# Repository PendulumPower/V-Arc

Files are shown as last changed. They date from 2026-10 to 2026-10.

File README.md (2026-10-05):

# V-ARC (WIP)
V-ARC is a multi-effects pedal, preamp, ble page turner, and looper designed for electric violin. It can also be used for other electric
instruments such as guitar. It runs on 2 separate controllers and includes a Lipo battery. It will be capable of being wirelessly reprogrammed for convienience,
and should have an app later in development so that settings can be tweaked or effects swapped without interacting with it. It is also going to feature MIDI conversion
and wireless playback in the future.
<br>Images:
<br>Schematic:
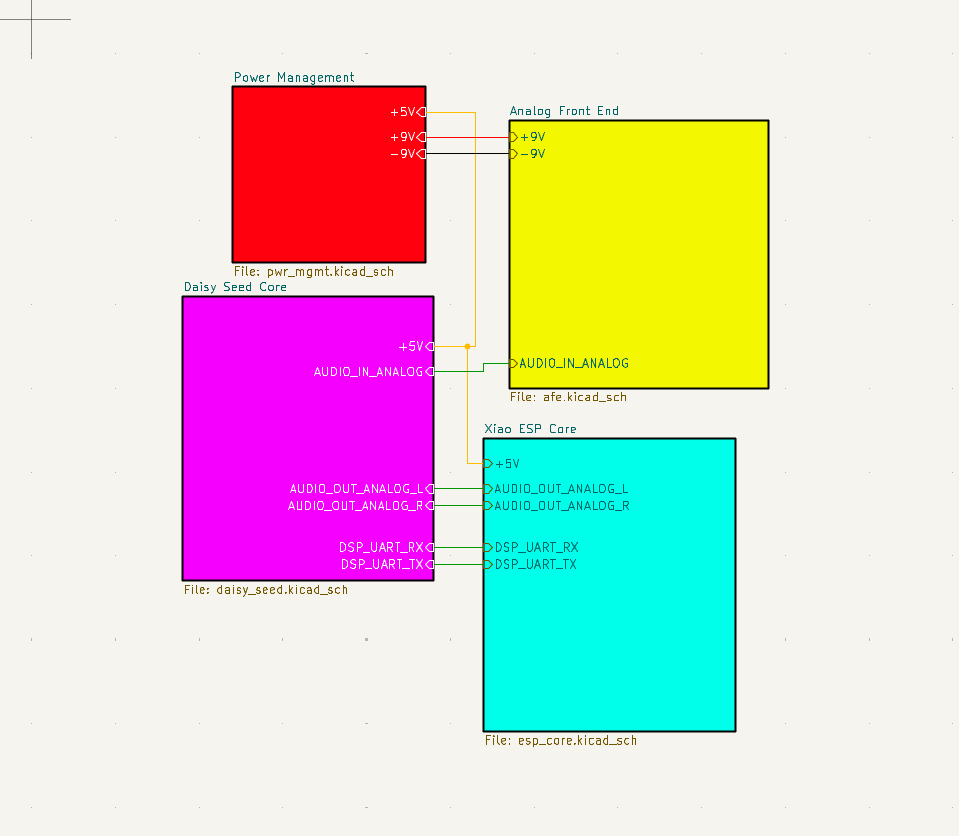
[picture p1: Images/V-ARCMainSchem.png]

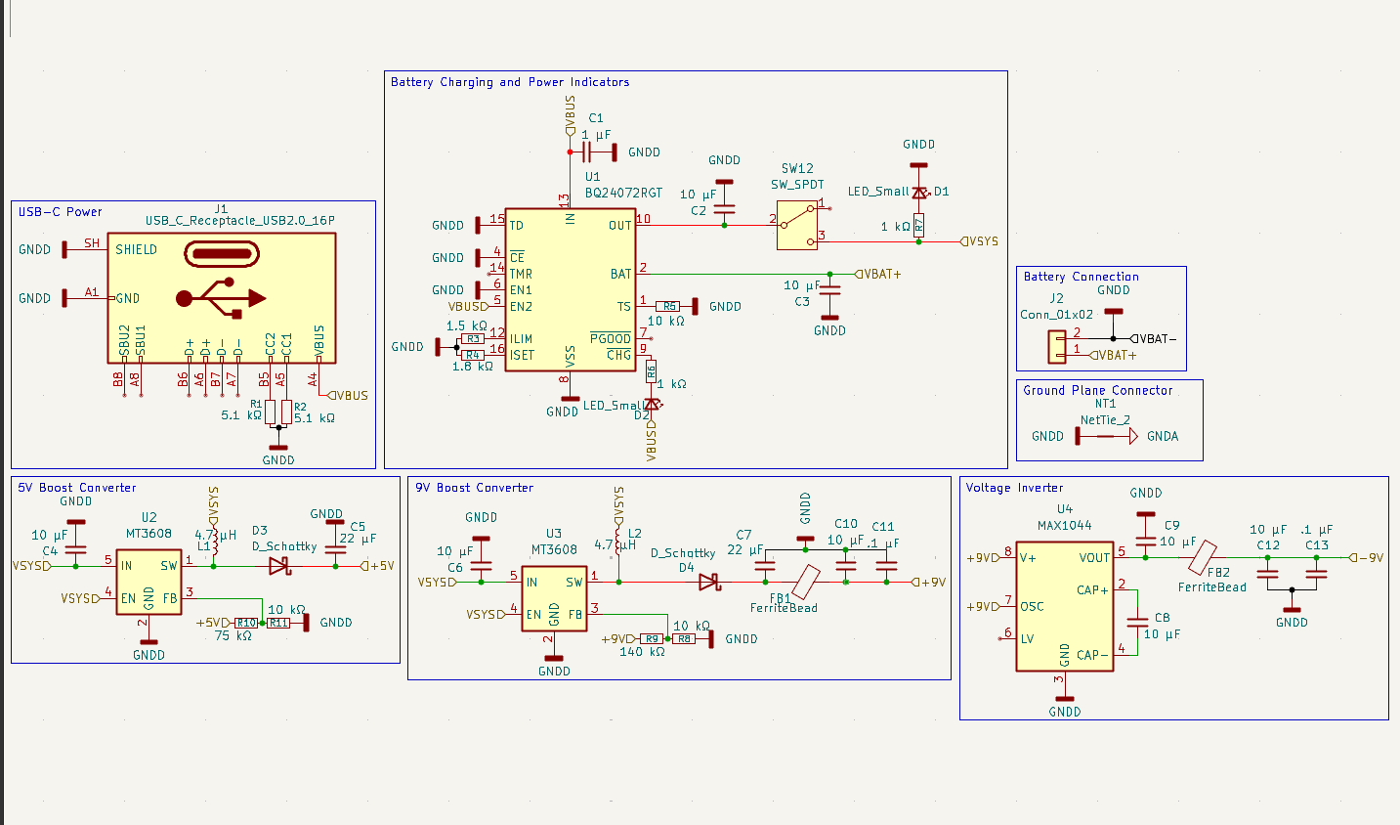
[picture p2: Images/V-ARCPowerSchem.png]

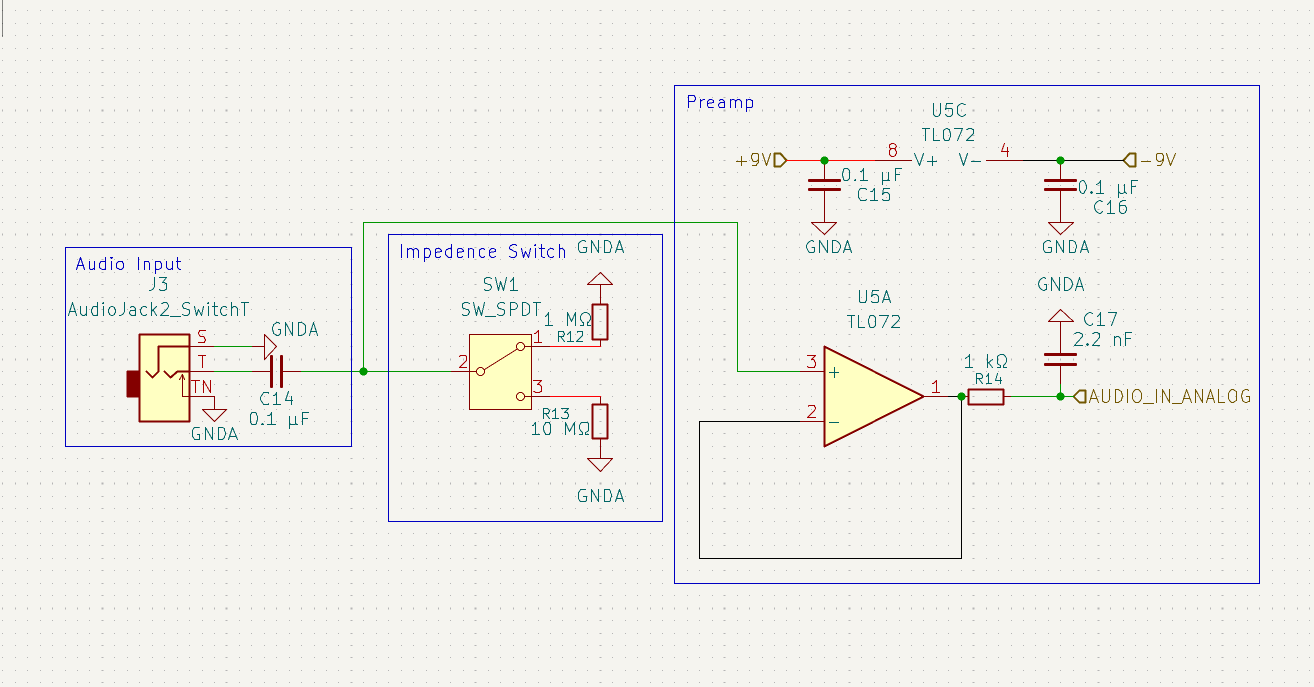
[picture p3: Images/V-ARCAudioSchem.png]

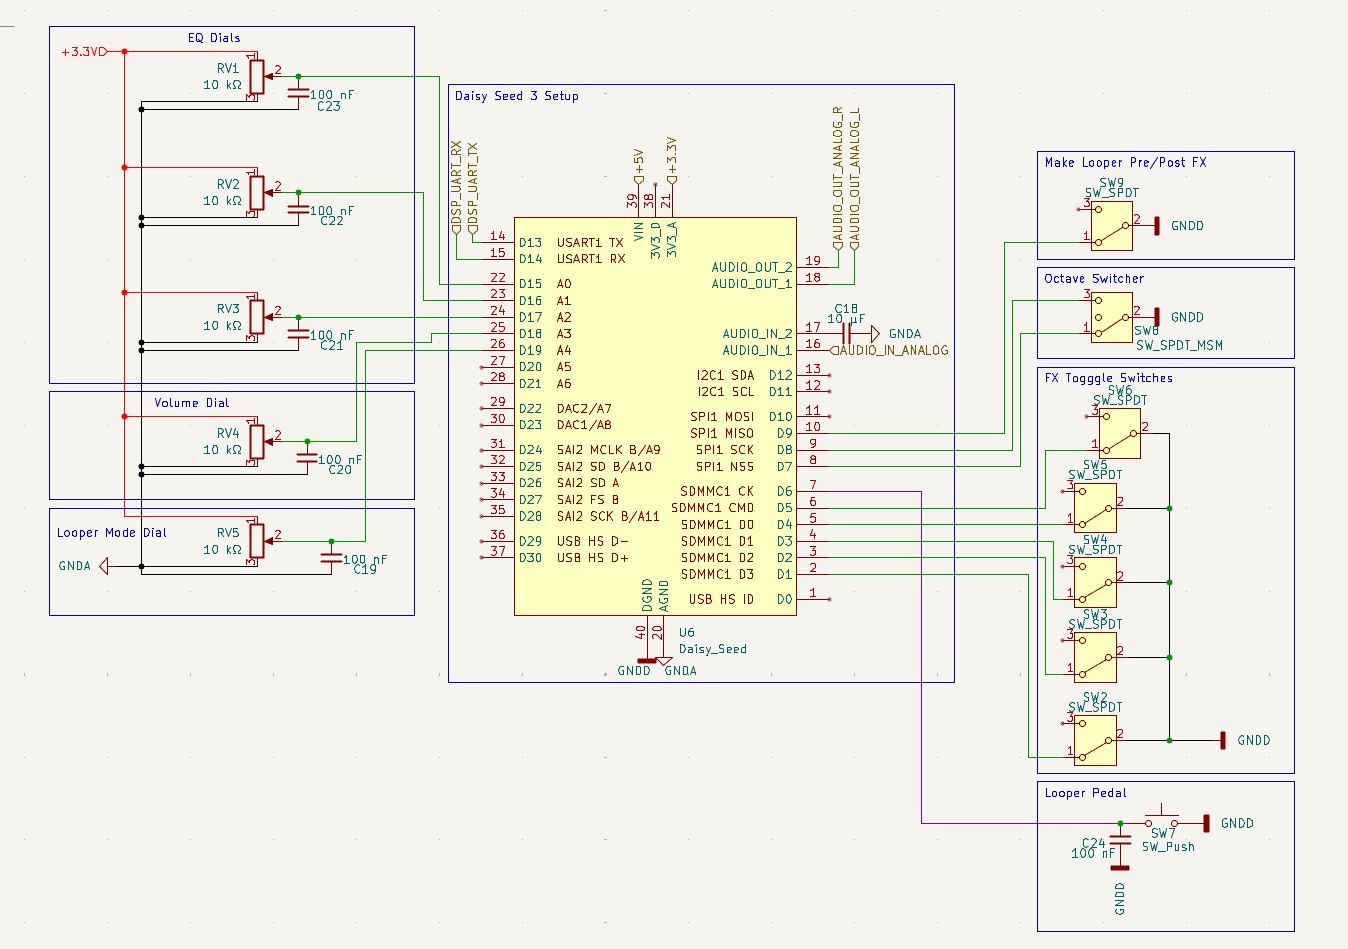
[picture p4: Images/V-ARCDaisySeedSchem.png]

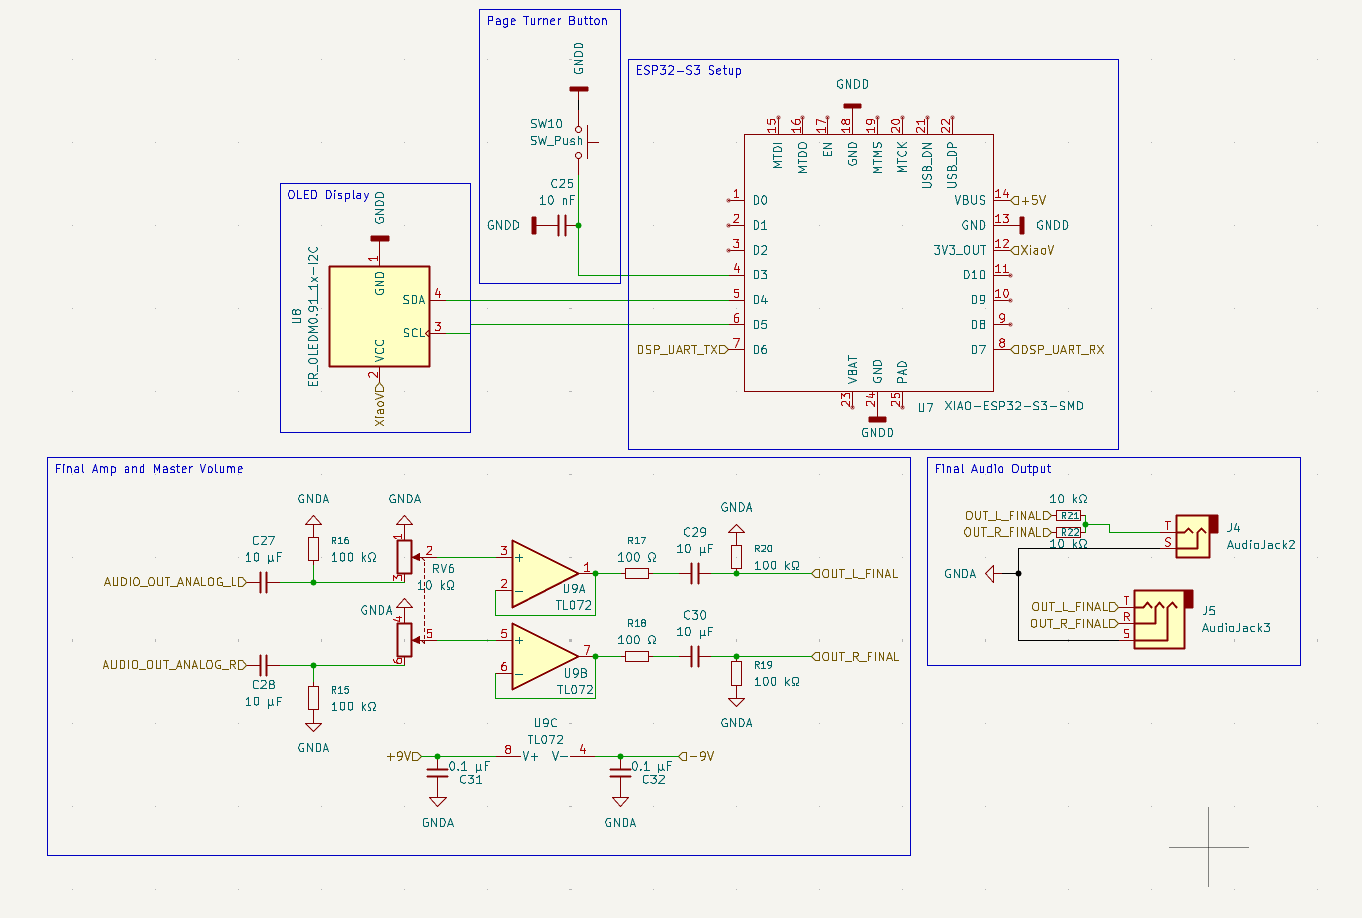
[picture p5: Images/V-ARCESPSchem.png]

<br>PCB:
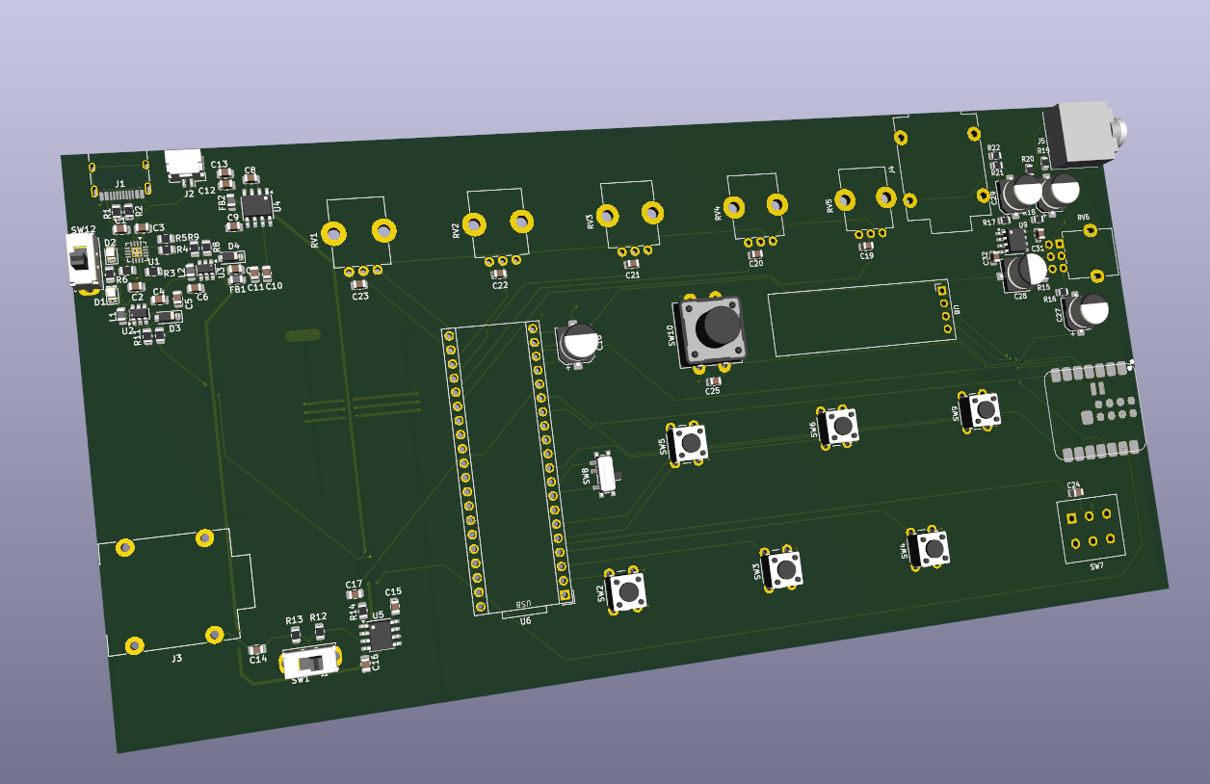
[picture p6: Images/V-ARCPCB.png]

<br>Cost Breakdown:
<br>-Digikey components+Tax+Tariff+Shipping: ~$80
<br>Dasiy seed3+Tax+Shipping: ~$40
<br>PCB+Stencil+Tax+Shipping: ~$35
<br>Total: ~$155

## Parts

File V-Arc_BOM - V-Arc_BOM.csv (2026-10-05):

Reference | Qty | Value | MPN | Footprint | Link | EXT_Price_USD | Total Component Cost
C1 | 1 | 1 µF | AC0805KKX7R8BB105 | Capacitor_SMD:C_0805_2012Metric | https://www.digikey.com/en/products/detail/yageo/AC0805KKX7R8BB105/6643137 | $0.39 | $89.77
C2,C3,C4,C6,C8,C9,C10,C12 | 8 | 10 µF | GMC21X5R106M10NT | Capacitor_SMD:C_0805_2012Metric | https://www.digikey.com/en/products/detail/cal-chip-electronics-inc/GMC21X5R106M10NT/25622741 | $1.52
C5,C7 | 2 | 22 µF | GMC21X5R226M10NT | Capacitor_SMD:C_0805_2012Metric | https://www.digikey.com/en/products/detail/cal-chip-electronics-inc/GMC21X5R226M10NT/25672174 | $0.72
C11,C13 | 2 | .1 µF | CC0805KRX7R6BB104 | Capacitor_SMD:C_0805_2012Metric | https://www.digikey.com/en/products/detail/yageo/CC0805KRX7R6BB104/11490895 | $0.34
C14 | 1 | 0.1 µF | CC0805KRX7R6BB104 | Capacitor_SMD:C_0805_2012Metric | https://www.digikey.com/en/products/detail/yageo/CC0805KRX7R6BB104/11490895 | $0.17
C15,C16,C31,C32 | 4 | 0.1 µF | CC0805KRX7R6BB104 | Capacitor_SMD:C_0805_2012Metric | https://www.digikey.com/en/products/detail/yageo/CC0805KRX7R6BB104/11490895 | $0.68
C17 | 1 | 2.2 nF | C0805C222K2GECTU | Capacitor_SMD:C_0805_2012Metric | https://www.digikey.com/en/products/detail/kemet/C0805C222K2GECTU/8644595 | $0.30
C18,C27,C28,C29,C30 | 5 | 10 µF | HHXC630ARA100MF61G | Capacitor_SMD:CP_Elec_6.3x5.4 | https://www.digikey.com/en/products/detail/chemi-con/HHXC630ARA100MF61G/6928179 | $4.10
C19,C20,C21,C22,C23,C24 | 6 | 100 nF | CC0805KRX7R6BB104 | Capacitor_SMD:C_0805_2012Metric | https://www.digikey.com/en/products/detail/yageo/CC0805KRX7R6BB104/11490895 | $1.02
C25 | 1 | 10 nF | C0805C103K1RECTU | Capacitor_SMD:C_0805_2012Metric | https://www.digikey.com/en/products/detail/kemet/C0805C103K1RECTU/8643869 | $0.33
D1,D2 | 2 | LED_Small | EAST2012WA1 | LED_SMD:LED_0805_2012Metric | https://www.digikey.com/en/products/detail/everlight-electronics-co-ltd/EAST2012WA1/11200795 | $0.46
D3,D4 | 2 | D_Schottky | MBR0520L | Diode_SMD:D_SOD-123 | https://www.digikey.com/en/products/detail/smc-diode-solutions/MBR0520L/13996701 | $1.18
FB1,FB2 | 2 | FerriteBead | ACML-0805-500-T | Inductor_SMD:L_0805_2012Metric | https://www.digikey.com/en/products/detail/abracon-llc/ACML-0805-500-T/4696694 | $0.22
J1 | 1 | USB_C_Receptacle_USB2.0_16P | USB4085-GF-A | Connector_USB:USB_C_Receptacle_HRO_TYPE-C-31-M-12 | https://www.digikey.be/en/products/detail/gct/USB4085-GF-A/9859662 | $0.91
J2 | 1 | Conn_01x02 | SM02B-GHS-TB | Connector_JST:JST_GH_SM02B-GHS-TB_1x02-1MP_P1.25mm_Horizontal | https://www.digikey.com/en/products/detail/jst-sales-america-inc/SM02B-GHS-TB/807786 | $0.35
J3 | 1 | AudioJack2_SwitchT | NMJ4HCD2 | Connector_Audio:Jack_6.35mm_Neutrik_NMJ4HCD2_Horizontal | https://www.digikey.com/en/products/detail/neutrik-americas-inc/NMJ4HCD2/29371256 | $2.53
J4 | 1 | AudioJack2 | NMJ4HCD2 | Connector_Audio:Jack_6.35mm_Neutrik_NMJ4HCD2_Horizontal | https://www.digikey.com/en/products/detail/neutrik-americas-inc/NMJ4HCD2/29371256 | $2.53
J5 | 1 | AudioJack3 | SJ1-3523N | Connector_Audio:Jack_3.5mm_CUI_SJ1-3523N_Horizontal | https://www.digikey.com/en/products/detail/same-sky-formerly-cui-devices/SJ1-3523N/738689 | $1.12
L1,L2 | 2 | 4.7 µH | ASMCI-0805-4R7M-T | Inductor_SMD:L_0805_2012Metric | https://www.digikey.com/en/products/detail/abracon-llc/ASMCI-0805-4R7M-T/4215145 | $0.42
R1,R2 | 2 | 5.1 kΩ | RT0805BRD075K1L | Resistor_SMD:R_0805_2012Metric | https://www.digikey.com/en/products/detail/yageo/RT0805BRD075K1L/1075977 | $0.20
R3 | 1 | 1.5 kΩ | RT0805DRE071K5L | Resistor_SMD:R_0805_2012Metric | https://www.digikey.com/en/products/detail/yageo/RT0805DRE071K5L/1078507 | $0.10
R4 | 1 | 1.8 kΩ | RC0805FR-071K82L | Resistor_SMD:R_0805_2012Metric | https://www.digikey.com/en/products/detail/yageo/RC0805FR-071K82L/727523 | $0.10
R5,R8,R11,R21,R22 | 5 | 10 kΩ | RC0805FR-0710KP | Resistor_SMD:R_0805_2012Metric | https://www.digikey.com/en/products/detail/yageo/RC0805FR-0710KP/4935334 | $0.65
R6,R7,R14 | 3 | 1 kΩ | RCA08051K00JNEA | Resistor_SMD:R_0805_2012Metric | https://www.digikey.com/en/products/detail/vishay-dale/RCA08051K00JNEA/4946804 | $0.42
R9 | 1 | 140 kΩ | RC0805FR-07140KL | Resistor_SMD:R_0805_2012Metric | https://www.digikey.com/en/products/detail/yageo/RC0805FR-07140KL/727602 | $0.10
R10 | 1 | 75 kΩ | CRCW080575K0FKEA | Resistor_SMD:R_0805_2012Metric | https://www.digikey.com/en/products/detail/vishay-dale/CRCW080575K0FKEA/1175851 | $0.10
R12 | 1 | 1 MΩ | RNCF0805DTE1M00 | Resistor_SMD:R_0805_2012Metric | https://www.digikey.com/en/products/detail/stackpole-electronics-inc/RNCF0805DTE1M00/1708252 | $0.10
R13 | 1 | 10 MΩ | RC0805FR-0710ML | Resistor_SMD:R_0805_2012Metric | https://www.digikey.com/en/products/detail/yageo/RC0805FR-0710ML/727536 | $0.11
R15,R16,R19,R20 | 4 | 100 kΩ | RT0805FRE10100KL | Resistor_SMD:R_0805_2012Metric | https://www.digikey.com/en/products/detail/yageo/RT0805FRE10100KL/17022986 | $0.40
R17,R18 | 2 | 100 Ω | AC0805JR-07100RL | Resistor_SMD:R_0805_2012Metric | https://www.digikey.com/en/products/detail/yageo/AC0805JR-07100RL/5897042 | $0.20
RV1,RV2,RV3,RV4,RV5 | 5 | 10 kΩ | MCU08050C1002FP500 | Potentiometer_THT:Potentiometer_Bourns_PTV09A-1_Single_Vertical | https://www.digikey.com/en/products/detail/vishay/MCU08050C1002FP500/2607870 | $0.55
RV6 | 1 | 10 kΩ | PTD902-2215K-B103 | Potentiometer_THT:Potentiometer_Alpha_RD902F-40-00D_Dual_Vertical | https://www.digikey.com/en/products/detail/bourns-inc/PTD902-2215K-B103/24635169?gclsrc=aw.ds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 | $2.40
SW1,SW12 | 2 | SW_SPDT | OS102011MS2QN1 | Button_Switch_THT:SW_Slide_SPDT_Straight_CK_OS102011MS2Q | https://www.digikey.com/en/products/detail/c-k/OS102011MS2QN1/411602 | $1.60
SW2,SW3,SW4,SW5,SW6,SW9 | 6 | SW_SPDT | 1301.9303 | Button_Switch_THT:SW_PUSH_6mm | https://www.digikey.com/en/products/detail/schurter-inc/1301-9303/3189753 | $3.60
SW7 | 1 | SW_Push | FS5700DPMT2B2M1QEH | Button_Switch_THT:SW_PUSH_E-Switch_FS5700DP_DPDT | https://www.digikey.com/en/products/detail/e-switch/FS5700DPMT2B2M1QEH/6825407 | $7.95
SW8 | 1 | SW_SPDT_MSM | PCM12SMTR | Button_Switch_SMD:SW_SPDT_PCM12 | https://www.digikey.com/en/products/detail/c-k/PCM12SMTR/1640112 | $1.28
SW10 | 1 | SW_Push | 430476085716 | Button_Switch_THT:SW_PUSH-12mm_Wuerth-430476085716 | http://digikey.com/en/products/detail/w%C3%BCrth-elektronik/430476085716/5209048 | $0.50
U1 | 1 | BQ24072RGT | BQ24072TRGTR | Package_DFN_QFN:VQFN-16-1EP_3x3mm_P0.5mm_EP1.6x1.6mm | https://www.digikey.com/en/products/detail/texas-instruments/BQ24072TRGTR/2279244 | $2.42
U2,U3 | 2 | MT3608 | TLV61048DBVR | Package_TO_SOT_SMD:SOT-23-6 | https://www.digikey.com/en/products/detail/texas-instruments/TLV61048DBVR/10715594?gclsrc=aw.ds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 | $1.80
U4 | 1 | MAX1044 | MAX1044ESA+T | Package_SO:SOIC-8_3.9x4.9mm_P1.27mm | https://www.digikey.com/en/products/detail/analog-devices-inc-maxim-integrated/MAX1044ESA-T/1428729 | $7.55
U5,U9 | 2 | TL072 | TL072CDT | Package_SO:SOIC-8_3.9x4.9mm_P1.27mm | https://www.digikey.com/en/products/detail/stmicroelectronics/TL072CDT/599372 | $0.86
U6 | 1 | Daisy_Seed |  | Daisy-Boards:DAISY_SEED | https://daisy.audio/products/seed3 | $30.00
U7 | 1 | XIAO-ESP32-S3-SMD | 113991114 | Seeed_Studio_XIAO_Series:XIAO-ESP32-S3-SMD | https://www.digikey.com/en/products/detail/seeed-technology-co-ltd/113991114/19285530 | $7.49

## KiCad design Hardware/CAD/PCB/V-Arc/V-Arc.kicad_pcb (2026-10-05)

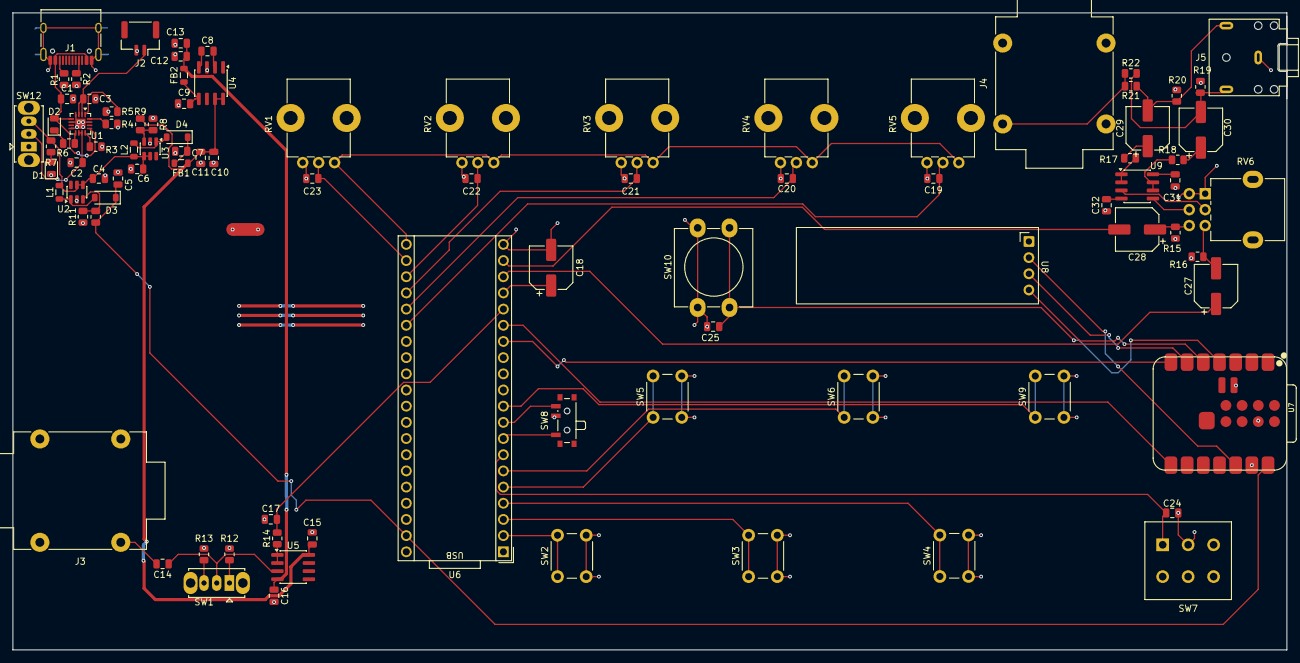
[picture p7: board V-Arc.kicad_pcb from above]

Board: 2 copper layers, 200.0 x 100.0 mm, 93 parts (0 on the bottom side), 68 nets.

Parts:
C1: 1 µF; C_0805_2012Metric
C2, C3, C4, C6, C8, C9, C10, C12: 10 µF; C_0805_2012Metric
C5, C7: 22 µF; C_0805_2012Metric
C11, C13: .1 µF; C_0805_2012Metric
C14, C15, C16, C31, C32: 0.1 µF; C_0805_2012Metric
C17: 2.2 nF; C_0805_2012Metric
C18, C27, C28, C29, C30: 10 µF; CP_Elec_6.3x5.4
C19, C20, C21, C22, C23, C24: 100 nF; C_0805_2012Metric
C25: 10 nF; C_0805_2012Metric
D1, D2: LED_Small; LED_0805_2012Metric
D3, D4: D_Schottky; D_SOD-123
FB1, FB2: FerriteBead; L_0805_2012Metric
J1: USB_C_Receptacle_USB2.0_16P; USB_C_Receptacle_HRO_TYPE-C-31-M-12
J2: Conn_01x02; JST_GH_SM02B-GHS-TB_1x02-1MP_P1.25mm_Horizontal
J3: AudioJack2_SwitchT; Jack_6.35mm_Neutrik_NMJ4HCD2_Horizontal
J4: AudioJack2; Jack_6.35mm_Neutrik_NMJ4HCD2_Horizontal
J5: AudioJack3; Jack_3.5mm_CUI_SJ1-3523N_Horizontal
L1, L2: 4.7 µH; L_0805_2012Metric
NT1: NetTie_2; NetTie-2_SMD_Pad2.0mm
R1, R2: 5.1 kΩ; R_0805_2012Metric
R3: 1.5 kΩ; R_0805_2012Metric
R4: 1.8 kΩ; R_0805_2012Metric
R5, R8, R11, R21, R22: 10 kΩ; R_0805_2012Metric
R6, R7, R14: 1 kΩ; R_0805_2012Metric
R9: 140 kΩ; R_0805_2012Metric
R10: 75 kΩ; R_0805_2012Metric
R12: 1 MΩ; R_0805_2012Metric
R13: 10 MΩ; R_0805_2012Metric
R15, R16, R19, R20: 100 kΩ; R_0805_2012Metric
R17, R18: 100 Ω; R_0805_2012Metric
RV1, RV2, RV3, RV4, RV5: 10 kΩ; Potentiometer_Bourns_PTV09A-1_Single_Vertical
RV6: 10 kΩ; Potentiometer_Alpha_RD902F-40-00D_Dual_Vertical
SW1, SW12: SW_SPDT; SW_Slide_SPDT_Straight_CK_OS102011MS2Q
SW2, SW3, SW4, SW5, SW6, SW9: SW_SPDT; SW_PUSH_6mm
SW7: SW_Push; SW_PUSH_E-Switch_FS5700DP_DPDT
SW8: SW_SPDT_MSM; SW_SPDT_PCM12
SW10: SW_Push; SW_PUSH-12mm_Wuerth-430476085716
U1: BQ24072RGT; VQFN-16-1EP_3x3mm_P0.5mm_EP1.6x1.6mm
U2, U3: MT3608; SOT-23-6
U4: MAX1044; SOIC-8_3.9x4.9mm_P1.27mm
U5, U9: TL072; SOIC-8_3.9x4.9mm_P1.27mm
U6: Daisy_Seed; DAISY_SEED
U7: XIAO-ESP32-S3-SMD
U8: ER_OLEDM0.91_1x-I2C

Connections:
/Analog Front End/+9V: C10.1, C11.1, C15.1, FB1.1, R9.2, U4.7 (OSC), U4.8 (V+), U5.8 (V+)
/Analog Front End/-9V: C12.1, C13.1, C16.1, FB2.2, U5.4 (V-)
/Analog Front End/AUDIO_IN_ANALOG: C17.2, R14.2, U6.16 (AUDIO_IN_1)
/Daisy Seed Core/+3.3V: RV1.1, RV2.1, RV3.1, RV4.1, RV5.1, U6.21 (3V3_A)
/Daisy Seed Core/+5V: C5.2, D3.1 (K), R10.2, U6.39 (VIN), U7.14 (VBUS)
/Daisy Seed Core/AUDIO_OUT_ANALOG_L: C27.1, U6.18 (AUDIO_OUT_1)
/Daisy Seed Core/AUDIO_OUT_ANALOG_R: C28.2, U6.19 (AUDIO_OUT_2)
/Daisy Seed Core/DSP_UART_RX: U6.15 (D14), U7.8 (D7)
/Daisy Seed Core/DSP_UART_TX: U6.14 (D13), U7.7 (D6)
/Power Management/VBAT+: C3.2, J2.1, U1.2 (BAT), U1.3 (BAT)
/Power Management/VBUS: C1.1, D2.2 (A), J1.A4 (VBUS), J1.A9 (VBUS), J1.B4 (VBUS), J1.B9 (VBUS), U1.5 (EN2), U1.13 (IN)
/Power Management/VSYS: C4.1, C6.1, L1.1, L2.2, R7.2, SW12.3 (C), U2.4 (EN), U2.5 (IN), U3.4 (EN), U3.5 (IN)
/Xiao ESP Core/+9V: C31.1, U9.8 (V+)
/Xiao ESP Core/-9V: C32.1, U9.4 (V-)
/Xiao ESP Core/OUT_L_FINAL: C29.2, J5.T, R20.1, R21.2
/Xiao ESP Core/OUT_R_FINAL: C30.2, J5.R, R19.2, R22.2
/Xiao ESP Core/XiaoV: U7.12 (3V3_OUT), U8.2 (VCC)
GNDA: C15.2, C16.2, C17.1, C18.2, C19.1, C20.1, C21.1, C22.1, C23.1, C31.2, C32.2, J3.S, J3.TN, J4.S, J5.S, NT1.2, R12.2, R13.2, R15.2, R16.1, R19.1, R20.2, RV1.3, RV2.3, RV3.3, RV4.3, RV5.3, RV6.1, RV6.4, U6.20 (AGND)
GNDD: C1.2, C2.2, C3.1, C4.2, C5.1, C6.2, C7.1, C9.2, C10.2, C11.2, C12.2, C13.2, C24.1, C25.1, D1.1 (K), J1.A1 (GND), J1.A12 (GND), J1.B1 (GND), J1.B12 (GND), J1.SH (SHIELD), J2.2, NT1.1, R1.2, R2.2, R3.2, R4.1, R5.1, R8.1, R11.1, SW2.2 (B), SW3.2 (B), SW4.2 (B), SW5.2 (B), SW6.2 (B), SW7.2, SW8.2 (3), SW9.2 (B), SW10.1, U1.4 (~CE), U1.6 (EN1), U1.8 (VSS), U1.15 (TD), U1.17 (VSS), U2.2 (GND), U3.2 (GND), U4.3 (GND), U6.40 (DGND), U7.13 (GND), U7.18 (GND), U7.24 (GND), U8.1 (GND)
unnamed: C14.2, J3.T
unnamed: C27.2, R16.2, RV6.3
unnamed: C28.1, R15.1, RV6.6
unnamed: C29.1, R17.2
unnamed: C30.1, R18.2
unnamed: D1.2 (A), R7.1
unnamed: D2.1 (K), R6.1
unnamed: D3.2 (A), L1.2, U2.1 (SW)
unnamed: D4.2 (A), L2.1, U3.1 (SW)
unnamed: C7.2, D4.1 (K), FB1.2
unnamed: J1.A5 (CC1), R2.1
unnamed: J1.B5 (CC2), R1.1
unnamed: J4.T, R21.1, R22.1
unnamed: R12.1, SW1.1 (A)
unnamed: C14.1, SW1.2 (B), U5.3 (+)
unnamed: R13.1, SW1.3 (C)
unnamed: SW2.1 (A), U6.2 (D1)
unnamed: SW3.1 (A), U6.3 (D2)
unnamed: SW4.1 (A), U6.4 (D3)
unnamed: SW5.1 (A), U6.5 (D4)
unnamed: SW6.1 (A), U6.6 (D5)
unnamed: SW8.3 (4), U6.9 (D8)
unnamed: SW9.1 (A), U6.10 (D9)
unnamed: C2.1, SW12.2 (B), U1.10 (OUT), U1.11 (OUT)
unnamed: R3.1, U1.12 (ILIM)
unnamed: R4.2, U1.16 (ISET)
unnamed: R5.2, U1.1 (TS)
unnamed: R6.2, U1.9 (~CHG)
unnamed: R10.1, R11.2, U2.3 (FB)
unnamed: R8.2, R9.1, U3.3 (FB)
unnamed: C8.2, U4.2 (CAP+)
unnamed: C8.1, U4.4 (CAP-)
unnamed: C9.1, FB2.1, U4.5 (VOUT)
unnamed: R14.1, U5.1, U5.2 (-)
unnamed: C18.1, U6.17 (AUDIO_IN_2)
unnamed: C24.2, SW7.1, U6.7 (D6)
unnamed: SW8.1, U6.8 (D7)
unnamed: C23.2, RV1.2, U6.22 (D15)
unnamed: C22.2, RV2.2, U6.23 (D16)
unnamed: C21.2, RV3.2, U6.24 (D17)
unnamed: C20.2, RV4.2, U6.25 (D18)
unnamed: C19.2, RV5.2, U6.26 (D19)
unnamed: C25.2, SW10.2, U7.4 (D3)
unnamed: U7.5 (D4), U8.4 (SDA)
unnamed: U7.6 (D5), U8.3 (SCL)
unnamed: RV6.2, U9.3 (+)
unnamed: R17.1, U9.1, U9.2 (-)
unnamed: RV6.5, U9.5 (+)
unnamed: R18.1, U9.6 (-), U9.7

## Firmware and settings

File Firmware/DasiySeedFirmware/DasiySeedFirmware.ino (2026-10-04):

//Par Gunderson
//10/04/2026
//V-ARC Daisy Seed Firmware
#include "DaisyDuino.h"
Uart hwSerial(14, 15);
using namespace daisysp;
DaisyHardware hw;

// Init Pots
enum PotIndices {
  POT_EQ1 = 0,
  POT_EQ2,
  POT_EQ3,
  POT_VOL,
  POT_HAZE,
  NUM_POTS
};

//Map pins
const int pot_pins[NUM_POTS] = {A0, A1, A2, A3, A4};

//Init Switches
Switch sw_looper_pre_post;
Switch sw_octave_up;
Switch sw_octave_down;
Switch sw_fx[5];
Switch sw_looper_stomp;

//Audio vars
float master_gain = 1.0f;
bool fx1_active = false;

void AudioCallback(float **in, float **out, size_t size) {
  hw.ProcessAnalogControls();
  hw.ProcessDigitalControls();

  //Process Controls
  master_gain = hw.GetKnobValue(POT_VOL);
  fx1_active = sw_fx[0].Pressed();

  for (size_t i = 0; i < size; i++) {
    float in_l = in[0][i];
    float in_r = in[1][i];

    float out_l = in_l * master_gain;
    float out_r = in_r * master_gain;

    out[0][i] = out_l;
    out[1][i] = out_r;
  }
}

void setup() {
  //Init Daisyduino
  hw = DAISY.init(DAISY_SEED, AUDIO_SR_48K);
  
  //Set block size
  DAISY.SetAudioBlockSize(4);

 //Config Pots
  pinMode(pot_pins[POT_EQ1], INPUT);
  pinMode(pot_pins[POT_EQ2], INPUT);
  pinMode(pot_pins[POT_EQ3], INPUT);
  pinMode(pot_pins[POT_VOL], INPUT);
  pinMode(pot_pins[POT_HAZE], INPUT);

  //Config Switches
  sw_looper_pre_post.Init(1000.0f, true, 12, INPUT_PULLUP);
  sw_octave_up.Init(1000.0f, true, 11, INPUT_PULLUP);
  sw_octave_down.Init(1000.0f, true, 10, INPUT_PULLUP);

  int fx_pins[5] = {9, 8, 7, 6, 5};
  for (int i = 0; i < 5; i++) {
    sw_fx[i].Init(1000.0f, true, fx_pins[i], INPUT_PULLUP);
  }
  sw_looper_stomp.Init(1000.0f, true, 4, INPUT_PULLUP);

  //Config UART
  hwSerial.begin(115200);

  //Start Audio
  DAISY.begin(AudioCallback);
}

void loop() {
  //Debounce Switches
  sw_looper_pre_post.Debounce();
  sw_octave_up.Debounce();
  sw_octave_down.Debounce();
  for (int i = 0; i < 5; i++) {
    sw_fx[i].Debounce();
  }
  sw_looper_stomp.Debounce();

  //UART Check
  if (hwSerial.available() >= 1) {
    uint8_t rx_buf[8];
    
    int bytesRead = hwSerial.readBytes(rx_buf, 1); 
    if (bytesRead > 0) {
       // Run received command :) (WIP)
    }
  }

  delay(5);
}

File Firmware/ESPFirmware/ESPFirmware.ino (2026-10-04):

//Par Gunderson
//10/04/2026
//V-ARC ESP32-S3 Firmware
#include <Arduino.h>
#include <Wire.h>
#include <Adafruit_GFX.h>
#include <Adafruit_SSD1306.h>
#include <BleKeyboard.h>

//Pin Defs
#define PIN_SW_PAGE D1
#define OLED_SDA    D4
#define OLED_SCL    D5
#define UART_TX     D6
#define UART_RX     D7

//OLED Setup
#define SCREEN_WIDTH 128
#define SCREEN_HEIGHT 32
Adafruit_SSD1306 display(SCREEN_WIDTH, SCREEN_HEIGHT, &Wire, -1);

//BLE Setup
BleKeyboard bleKeyboard("Violin Pedalboard", "Custom", 100);

//Pedal time vars
const unsigned long DEBOUNCE_DELAY = 50;
const unsigned long HOLD_THRESHOLD = 500;

//Button State vars
unsigned long press_start_time = 0;
bool is_pressed = false;
bool hold_action_triggered = false;

void setup() {
    //Init Switch
    pinMode(PIN_SW_PAGE, INPUT_PULLUP);

    //Init UART
    Serial1.begin(115200, SERIAL_8N1, UART_RX, UART_TX);

    //Init I2C and OLED
    Wire.begin(OLED_SDA, OLED_SCL);
    if (display.begin(SSD1306_SWITCHCAPVCC, 0x3C)) {
        display.clearDisplay();
        display.setTextSize(1);
        display.setTextColor(SSD1306_WHITE);
        display.setCursor(0, 0);
        display.println("V-ARC");
        display.println("BLE: Pairing...");
        display.display();
    }

    //Start BLE
    bleKeyboard.begin();
}

void loop() {
    bool current_state = digitalRead(PIN_SW_PAGE);

    if (bleKeyboard.isConnected()) {
        //Check Pressed
        if (current_state == LOW && !is_pressed) {
            is_pressed = true;
            press_start_time = millis();
            hold_action_triggered = false;
        }

        if (is_pressed && current_state == LOW) {
            //Check held
            if (!hold_action_triggered && (millis() - press_start_time >= HOLD_THRESHOLD)) {
                bleKeyboard.write(KEY_LEFT_ARROW);
                hold_action_triggered = true;
                
                //Tell daisy
                Serial1.write(0xA1);
            }
        }
        
        if (current_state == HIGH && is_pressed) {
            unsigned long press_duration = millis() - press_start_time;
            is_pressed = false;

            //When Tapped
            if (!hold_action_triggered && (press_duration >= DEBOUNCE_DELAY)) {
                bleKeyboard.write(KEY_RIGHT_ARROW);
                
                //Tell daisy
                Serial1.write(0xA2);
            }
        }
    }

    //Update Display
    static unsigned long last_ui_update = 0;
    if (millis() - last_ui_update > 250) {
        last_ui_update = millis();
        display.clearDisplay();
        display.setCursor(0, 0);
        display.print("BLE: ");
        display.println(bleKeyboard.isConnected() ? "CONNECTED" : "WAITING...");
        
        display.setCursor(0, 16);
        display.println("DSP STATUS: ACTIVE");
        display.display();
    }
}

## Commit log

2026-09-25 Add KiCad project files for V-Arc PCB
    Add full KiCad project for V-Arc: board file (V-Arc.kicad_pcb), project prefs (.kicad_prl, .kicad_pro), top-level schematic (V-Arc.kicad_sch) and detailed power-management schematic (pwr_mgmt.kicad_s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
    [V-Arc.kicad_pcb, V-Arc.kicad_sch, pwr_mgmt.kicad_sch]
2026-09-26 Added more sheets to the schematic
    -Added audio front end sheet
    -Added Daisy Seed 3 core sheet
    [V-Arc.kicad_sch, afe.kicad_sch, daisy_seed.kicad_sch]
2026-09-27 Added a sheet and organized
    -Added XIAO ESP32 Core sheet
    -Titled all sheets
    -Added power switch to the power sheet
    -Organized all sheets with text boxes
    [V-Arc.kicad_sch, afe.kicad_sch, daisy_seed.kicad_sch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]
2026-09-27 Licensing
    -Put firmware under MIT
    -Put Hardware under custom license
    [V-Arc.kicad_pcb, V-Arc.kicad_sch, afe.kicad_sch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]
2026-10-02 Assigned Footprints
    -Swapped input jack to a switched one
    -Assigned footprints for all items
    [V-Arc.kicad_sch, afe.kicad_sch, daisy_seed.kicad_sch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]
2026-10-03 Started PCB
    [V-Arc.kicad_pcb, afe.kicad_sch, pwr_mgmt.kicad_sch]
2026-10-03 Finished PCB Layout
    [V-Arc.kicad_pcb, esp_core.kicad_sch]
2026-10-04 Wired and Connected some zones
    [V-Arc.kicad_pcb]
2026-10-04 Finished PCB
    [V-Arc.kicad_pcb, daisy_seed.kicad_sch]
2026-10-05 Added BOM
    [V-Arc.kicad_pcb, V-Arc_BOM - V-Arc_BOM.csv, afe.kicad_sch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]
2026-10-05 Added images and gerbers
    [V-Arc.kicad_pcb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]
